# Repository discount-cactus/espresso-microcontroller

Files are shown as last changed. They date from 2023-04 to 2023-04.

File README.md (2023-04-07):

# Espresso

Rev1

The main goal of the project is to design the most simple, barebones microcontroller board possible and then compliment the board with supporting modules to ultimately achieve a modular microcontroller that can be configured for a multitude of projects that a generic microcontroller can be used for.

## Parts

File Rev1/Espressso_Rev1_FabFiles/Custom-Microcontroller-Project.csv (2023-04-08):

Source: | /Users/brandonlantau/Desktop/Microcontroller Design/espresso-microcontroller/Rev1/Custom-Microcontroller-Project/Custom-Microcontroller-Project.kicad_sch
Date: | Saturday, April 08, 2023 at 01:26:25 PM
Tool: | Eeschema (7.0.0-0)
Generator: | /Applications/KiCad/KiCad.app/Contents/SharedSupport/plugins/bom_csv_grouped_by_value.py
Component Count: | 69
Collated Components:
Item | Qty | Reference(s) | Value | LibPart | Footprint | Datasheet | DNP | MANUFACTURER | Part Number
1 | 1 | ANT1 | U.FL-R-SMT-1(10) | Custom_Microcontroller:U.FL-R-SMT-1(10) | Custom_Microcontroller:HRS_U.FL-R-SMT-1(10) |  |  |  | Hirose
2 | 2 | C1, C6 | 10uF | Custom_Microcontroller:C_0603_10uF | Custom_Microcontroller:C_0603
3 | 5 | C2, C8, C10, C17, C18 | 1uF | Custom_Microcontroller:C_0603_1uF | Custom_Microcontroller:C_0603
4 | 11 | C3, C9, C11, C12, C13, C14, C15, C19, C21, C24, C25 | 100nF | Custom_Microcontroller:C_0603_100nF | Custom_Microcontroller:C_0603
5 | 2 | C4, C5 | 12pF | Custom_Microcontroller:C_0603_12pF | Custom_Microcontroller:C_0603
6 | 2 | C7, C16 | 10nF | Custom_Microcontroller:C_0603_10nF | Custom_Microcontroller:C_0603
7 | 1 | C20 | 4.7uF | Custom_Microcontroller:C_0603_4.7uF | Custom_Microcontroller:C_0603
8 | 2 | C22, C23 | 20pF | Custom_Microcontroller:C_0603_20pF | Custom_Microcontroller:C_0603
9 | 2 | D1, D2 | LTST-C191KGKT | Custom_Microcontroller:LED_0603_Orange | Custom_Microcontroller:LED_0603
10 | 2 | J1, J3 | 10118193-0001LF | Custom_Microcontroller:10118193-0001LF | Custom_Microcontroller:10118193-0001LF |  |  |  | Amphenol FCI
11 | 2 | J2, J5 | PPTC202LFBN-RC | Custom_Microcontroller:HEADER-2x20 | Custom_Microcontroller:2X20
12 | 7 | J4, J6, J7, J9, J10, J11, J12 | ~ | Custom_Microcontroller:HEADER-1X2 | Custom_Microcontroller:1X2
13 | 3 | L1, L2, L3 | 4.7nH | Custom_Microcontroller:L_0603_4.7nH | Custom_Microcontroller:L_0603 |  |  |  |  | LMCI1608-4N7ST
14 | 2 | R1, R4 | 470ohm | Custom_Microcontroller:R_0603_470ohm | Custom_Microcontroller:R_0603 |  |  |  |  | RMCF0603FT470R
15 | 4 | R2, R3, R7, R9 | 10k | Custom_Microcontroller:R_0603_10kohm | Custom_Microcontroller:R_0603 |  |  |  |  | RNCP0603FTD10K0
16 | 5 | R5, R6, R10, R11, R12 | 0ohm | Custom_Microcontroller:R_0603_0ohm | Custom_Microcontroller:R_0603 |  |  |  |  | RMCF0603ZT0R00
17 | 1 | R8 | 10ohm | Custom_Microcontroller:R_0603_10ohm | Custom_Microcontroller:R_0603 |  |  |  |  | RNCP0603FTD10R0
18 | 4 | R13, R14, R15, R16 | 1Mohm | Custom_Microcontroller:R_0603_1Mohm | Custom_Microcontroller:R_0603 |  |  |  |  | RMCF0603FG1M00
19 | 2 | S1, S2 | DS01C-254-L-06BE | Custom_Microcontroller:Switch_6POS | Custom_Microcontroller:SW_DS01C-254-L-06BE |  |  |  | CUI
20 | 2 | SW1, SW2 | PTS636_SK25J_SMTR_LFS | Custom_Microcontroller:PTS636_SK25J_SMTR_LFS | Custom_Microcontroller:PTS636 SK25J SMTR LFS
21 | 2 | U1, U3 | MIC5209-3.3YS | Custom_Microcontroller:MIC5209-3.3YS | Custom_Microcontroller:MIC5209-3.3YS
22 | 1 | U2 | ESP32-C3FH4 | Custom_Microcontroller:ESP32-C3FH4 | Custom_Microcontroller:QFN50P500X500X90-33N |  |  |  | Espressif
23 | 1 | U5 | ATSAMD21G18A-MUT | Custom_Microcontroller:ATSAMD21G18A-MUT | Custom_Microcontroller:ATSAMD21G18A-MUT
24 | 1 | Y1 | HCM4916000000ABJT | Custom_Microcontroller:Crystal_16MHz | Custom_Microcontroller:Crystal_16MHz
25 | 1 | Y2 | ECS-3951M-400-BN-TR | Custom_Microcontroller:ECS-3951M-400-BN-TR | Custom_Microcontroller:ECS-3951M-400-BN-TR
26 | 1 | Y3 | ABS07-32.768KHZ-9-T | Custom_Microcontroller:Crystal_32.768kHz | Custom_Microcontroller:Crystal_32.768kHz

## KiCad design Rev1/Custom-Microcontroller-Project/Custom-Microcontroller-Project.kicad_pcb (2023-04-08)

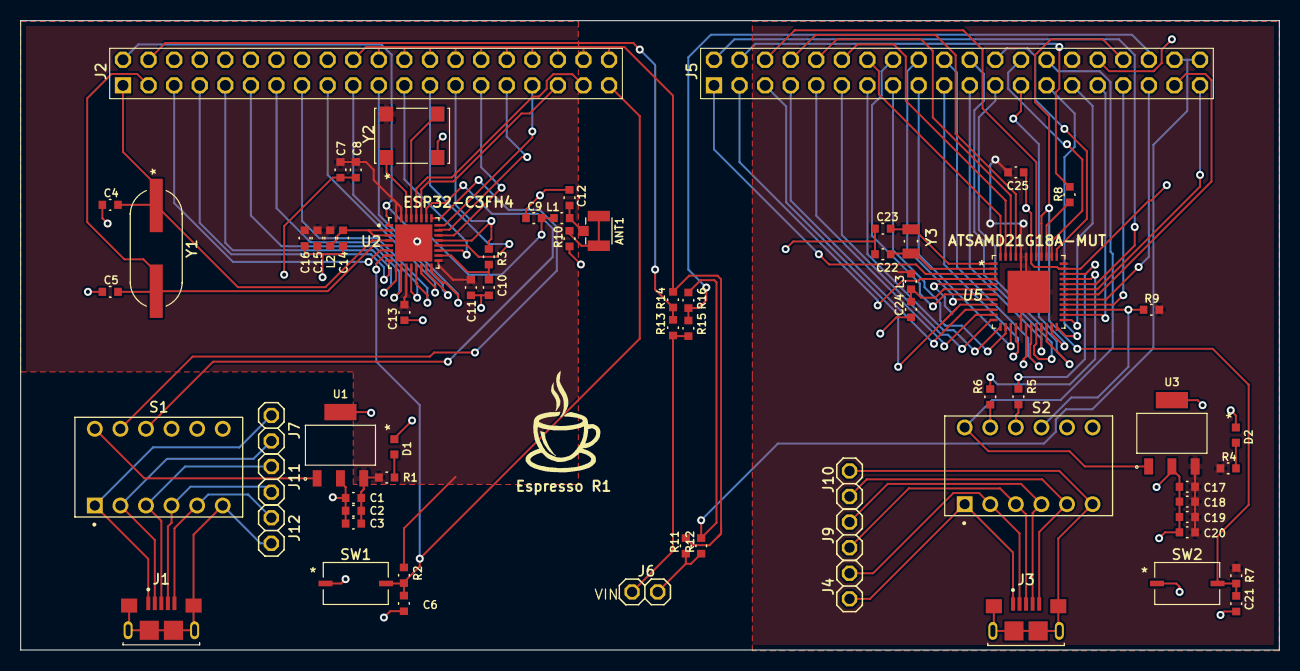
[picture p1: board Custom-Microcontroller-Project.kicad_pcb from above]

Board: 2 copper layers, 125.0 x 62.5 mm, 69 parts (0 on the bottom side), 98 nets.

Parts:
ANT1: U.FL-R-SMT-1(10); HRS_U.FL-R-SMT-1(10)
C1, C6: 10uF; C_0603
C2, C8, C10, C17, C18: 1uF; C_0603
C3, C9, C11, C12, C13, C14, C15, C19, C21, C24, C25: 100nF; C_0603
C4, C5: 12pF; C_0603
C7, C16: 10nF; C_0603
C20: 4.7uF; C_0603
C22, C23: 20pF; C_0603
D1, D2: LTST-C191KGKT; LED_0603
J1, J3: AMPHENOL_10118193-0001LF; 10118193-0001LF
J2, J5: PPTC202LFBN-RC; 2X20
J4, J6, J7, J9, J10, J11, J12: 1X2
L1, L2, L3: 4.7nH; L_0603
R1, R4: 470ohm; R_0603
R2, R3, R7, R9: 10k; R_0603
R5, R6, R10, R11, R12: 0ohm; R_0603
R8: 10ohm; R_0603
R13, R14, R15, R16: 1Mohm; R_0603
S1, S2: DS01C-254-L-06BE; SW_DS01C-254-L-06BE
SW1, SW2: PTS636_SK25J_SMTR_LFS; PTS636 SK25J SMTR LFS
U1, U3: SOT-223_S_MCH; MIC5209-3.3YS
U2: ESP32-C3FH4; QFN50P500X500X90-33N
U5: QFN48_7X7MC_MCH; ATSAMD21G18A-MUT
Y1: HCM4916000000ABJT; Crystal_16MHz
Y2: ECS-3951M-400-BN-TR
Y3: ABS07-32.768KHZ-9-T; Crystal_32.768kHz

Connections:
/ESP32 Board/ANT: C9.2, J2.P$21 (21), L1.1, U2.1 (LNA_IN)
/ESP32 Board/ESP32_3V3: C1.2, C2.2, C3.2, C7.2, C8.2, C11.2, C13.2, C15.2, C16.2, L2.2, R1.2, R2.2, U1.3 (OUT), U2.11 (VDD3P3_RTC), U2.17 (VDD3P3_CPU), U2.31 (VDDA), U2.32 (VDDA), Y2.4 (VCC)
/ESP32 Board/ESP32_D+: S1.3B, U2.26 (GPIO19)
/ESP32 Board/ESP32_D-: S1.2B, U2.25 (GPIO18)
/ESP32 Board/ESP32_GND: C1.1, C2.1, C3.1, C4.1, C5.1, C6.1, C7.1, C8.1, C9.1, C10.1, C11.1, C12.1, C13.1, C14.1, C15.1, C16.1, D1.1, J2.P$23 (23), J2.P$24 (24), J2.P$25 (25), J2.P$26 (26), J2.P$27 (27), J2.P$28 (28), J2.P$29 (29), R10.1, S1.5B, S1.6B, SW1.1, U1.2 (GND), U1.4 (GND), U2.33 (GND), Y2.2 (GROUND)
/ESP32 Board/ESP32_VIN: S1.1B, U1.1 (IN)
/ESP32 Board/GPIO_0: C4.2, J2.P$1 (1), U2.4 (XTAL_32K_P), Y1.1
/ESP32 Board/GPIO_1: C5.2, J2.P$2 (2), U2.5 (XTAL_32K_N), Y1.2
/ESP32 Board/GPIO_2: J2.P$3 (3), U2.6 (GPIO2)
/ESP32 Board/GPIO_3: J2.P$4 (4), U2.8 (GPIO3)
/ESP32 Board/GPIO_4: J2.P$5 (5), U2.9 (MTMS)
/ESP32 Board/GPIO_5: J2.P$6 (6), U2.10 (MTDI)
/ESP32 Board/GPIO_6: J2.P$7 (7), U2.12 (MTCK)
/ESP32 Board/GPIO_7: J2.P$8 (8), U2.13 (MTDO)
/ESP32 Board/GPIO_8: J2.P$9 (9), U2.14 (GPIO8)
/ESP32 Board/GPIO_9: J2.P$10 (10), U2.15 (GPIO9)
/ESP32 Board/GPIO_10: J2.P$11 (11), U2.16 (GPIO10)
/ESP32 Board/GPIO_11: J2.P$12 (12), U2.19 (SPIHD)
/ESP32 Board/GPIO_12: J2.P$13 (13), U2.20 (SPIWP)
/ESP32 Board/GPIO_13: J2.P$14 (14), R3.1, U2.21 (SPICS0)
/ESP32 Board/GPIO_14: J2.P$15 (15), U2.22 (SPICLK)
/ESP32 Board/GPIO_15: J2.P$16 (16), U2.23 (SPID)
/ESP32 Board/GPIO_16: J2.P$17 (17), U2.24 (SPIQ)
/ESP32 Board/GPIO_17: J2.P$18 (18), U2.27 (RX)
/ESP32 Board/GPIO_18: J2.P$19 (19), U2.28 (TX)
/ESP32 Board/RESET: C6.2, J2.P$20 (20), R2.1, SW1.2, U2.7 (CHIP_EN_(RESET))
/ESP32 Board/SPI_VDD: C10.2, R3.2, U2.18 (VDD_SPI)
/ESP32 Board/VIN_LVL: J2.P$22 (22), R13.1, R14.2
/ESP32 Board/V_GND: J2.P$30 (30), J2.P$31 (31), J2.P$32 (32), J2.P$33 (33), J2.P$34 (34), J2.P$35 (35), J2.P$36 (36), J2.P$37 (37), J2.P$38 (38), J2.P$39 (39), J2.P$40 (40), R11.2, R14.1
/GND: J6.2, R11.1, R12.1
/SAMD Board/GPIO_2: J5.P$1 (1), U5.3 (PA02/AIN0)
/SAMD Board/GPIO_3: J5.P$2 (2), U5.4 (PA03)
/SAMD Board/GPIO_4: J5.P$3 (3), U5.9 (PA04/AIN4)
/SAMD Board/GPIO_5: J5.P$4 (4), U5.10 (PA05/AIN5)
/SAMD Board/GPIO_6: J5.P$5 (5), U5.11 (PA06/AIN6)
/SAMD Board/GPIO_7: J5.P$6 (6), U5.12 (PA07/AAIN7)
/SAMD Board/GPIO_8: J5.P$7 (7), U5.13 (PA08/SDA)
/SAMD Board/GPIO_9: J5.P$8 (8), U5.14 (PA09/SCL)
/SAMD Board/GPIO_10: J5.P$9 (9), U5.15 (PA10)
/SAMD Board/GPIO_11: J5.P$10 (10), U5.16 (PA11)
/SAMD Board/GPIO_12: J5.P$11 (11), U5.21 (PA12/MOSI2)
/SAMD Board/GPIO_13: J5.P$12 (12), U5.22 (PA13/SCK2)
/SAMD Board/GPIO_14: J5.P$13 (13), U5.23 (PA14/NSS2)
/SAMD Board/GPIO_15: J5.P$14 (14), U5.24 (PA15/MISO2)
/SAMD Board/GPIO_16: J5.P$15 (15), U5.25 (PA16/MOSI1)
/SAMD Board/GPIO_17: J5.P$16 (16), U5.26 (PA17/SCK1)
/SAMD Board/GPIO_19: J5.P$17 (17), U5.28 (PA19/MISO1)
/SAMD Board/GPIO_20: J5.P$18 (18), U5.29 (PA20)
/SAMD Board/GPIO_21: J5.P$19 (19), U5.30 (PA21)
/SAMD Board/GPIO_22: J5.P$20 (20), U5.31 (PA22)
/SAMD Board/GPIO_23: J5.P$21 (21), U5.32 (PA23)
/SAMD Board/GPIO_27: J5.P$22 (22), R8.2
/SAMD Board/GPIO_28: J5.P$23 (23), U5.41 (PA28)
/SAMD Board/GPIO_30: J5.P$24 (24), U5.45 (PA30/SWCLK)
/SAMD Board/GPIO_31: J5.P$25 (25), U5.46 (PA31/SWDIO)
/SAMD Board/GPIO_32: J5.P$26 (26), U5.47 (PB02/AIN10)
/SAMD Board/GPIO_33: J5.P$27 (27), U5.48 (PB03/AIN11)
/SAMD Board/GPIO_34: J5.P$28 (28), U5.7 (PB08)
/SAMD Board/GPIO_35: J5.P$29 (29), U5.8 (PB09)
/SAMD Board/GPIO_36: J5.P$30 (30), U5.19 (PB10)
/SAMD Board/GPIO_37: J5.P$31 (31), U5.20 (PB11)
/SAMD Board/GPIO_38: J5.P$32 (32), U5.37 (PB22/TX)
/SAMD Board/GPIO_39: J5.P$33 (33), U5.38 (PB23/RX)
/SAMD Board/SAMD_3V3: C17.2, C18.2, C19.2, C20.2, C25.2, J5.P$35 (35), L3.2, R4.2, R7.2, R9.2, U3.3 (OUT), U5.17 (VDDIO), U5.36 (VDDIO), U5.43 (VDDCORE), U5.44 (VDDIN), U5.49 (EPAD)
/SAMD Board/SAMD_D+: R5.2, S2.3B
/SAMD Board/SAMD_D-: R6.2, S2.2B
/SAMD Board/SAMD_GND: C17.1, C18.1, C19.1, C20.1, C21.1, C22.1, C23.1, C24.1, C25.1, D2.1, J5.P$36 (36), S2.5B, S2.6B, SW2.1, U3.2 (GND), U3.4 (GND), U5.5 (GNDANA), U5.18 (GND), U5.35 (GND), U5.42 (GND)
/SAMD Board/SAMD_RESET: C21.2, J5.P$37 (37), R7.1, SW2.2, U5.40 (*RESET)
/SAMD Board/SAMD_USB_ID: R9.1, S2.4B, U5.27 (PA18)
/SAMD Board/SAMD_VIN: J5.P$34 (34), S2.1B, U3.1 (IN)
/SAMD Board/VIN_LVL: J5.P$38 (38), R15.1, R16.2
/SAMD Board/V_GND: J5.P$39 (39), J5.P$40 (40), R12.2, R16.1
/VIN: J6.1, R13.2, R15.2
unnamed: ANT1.1, ANT1.3, R10.2
unnamed: ANT1.2, C12.2, L1.2
unnamed: C14.2, L2.1, U2.2 (VDD3P3), U2.3 (VDD3P3)
unnamed: D1.2, R1.1
unnamed: D2.2, R4.1
unnamed: J1.3 (D+), J11.1, S1.3A
unnamed: J1.2 (D-), J7.2, S1.2A
unnamed: J1.5 (GND), J12.1, S1.5A
unnamed: J1.4 (ID), J11.2, S1.4A
unnamed: J1.S1 (SHIELD), J1.S2 (SHIELD), J1.S3 (SHIELD), J1.S4 (SHIELD), J1.S5 (SHIELD), J1.S6 (SHIELD), J12.2, S1.6A
unnamed: J1.1 (VUSB), J7.1, S1.1A
unnamed: J3.3 (D+), J9.1, S2.3A
unnamed: J3.2 (D-), J4.2, S2.2A
unnamed: J3.5 (GND), J10.1, S2.5A
unnamed: J3.4 (ID), J9.2, S2.4A
unnamed: J3.1 (VUSB), J4.1, S2.1A
unnamed: J3.S1 (SHIELD), J3.S2 (SHIELD), J3.S3 (SHIELD), J3.S4 (SHIELD), J3.S5 (SHIELD), J3.S6 (SHIELD), J10.2, S2.6A
unnamed: U2.29 (XTAL_N), Y2.3 (OUTPUT)
unnamed: U2.30 (XTAL_P), Y2.1 (TRI-STATE)
unnamed: C23.2, U5.1 (PA00/XIN32), Y3.2
unnamed: C22.2, U5.2 (PA01/XOUT32), Y3.1
unnamed: R6.1, U5.33 (PA24/USB_D-)
unnamed: R5.1, U5.34 (PA25/USB_D+)
unnamed: R8.1, U5.39 (PA27)
unnamed: C24.2, L3.1, U5.6 (VDDANA)

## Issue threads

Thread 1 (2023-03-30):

Espresso Rev1

discount-cactus, 2023-03-30:

discount-cactus, 2023-03-30:
- [ ] ESP32 board
- [ ] SAMD board

discount-cactus, 2023-04-08:
4/8/23: Fab files were out for quote. Release for Espresso Rev1 was generated.
